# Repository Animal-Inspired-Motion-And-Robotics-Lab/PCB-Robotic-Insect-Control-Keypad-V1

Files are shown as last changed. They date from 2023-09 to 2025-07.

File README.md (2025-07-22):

# Robotic-Insect-Control-Keypad-V1 (R.I.C.K.)

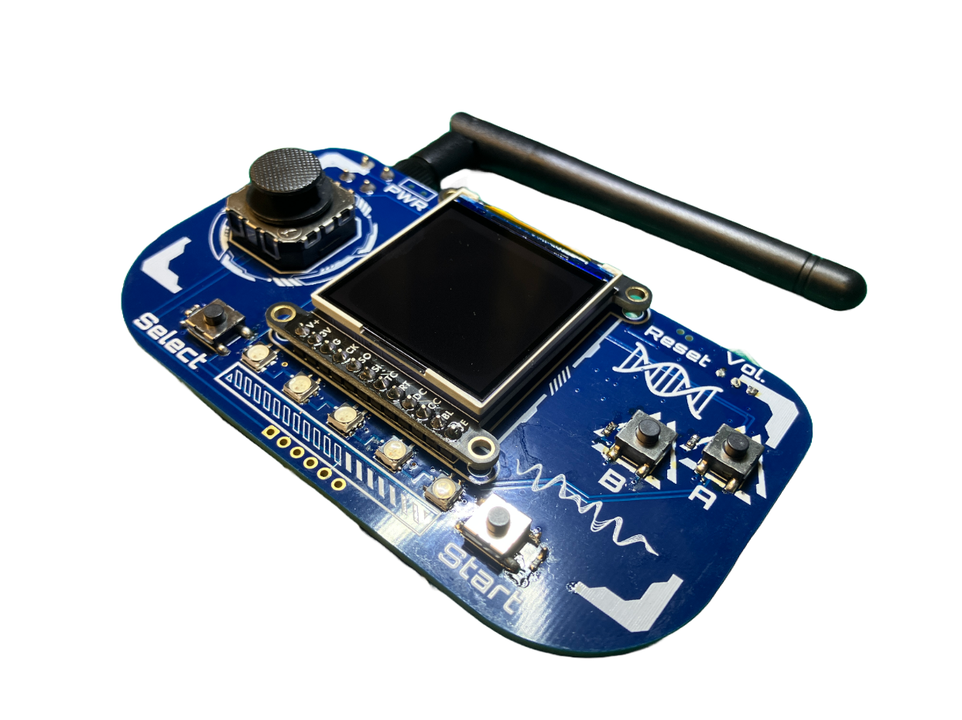
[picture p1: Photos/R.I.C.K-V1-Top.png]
R.I.C.K Top


## Description

The Robotic Insect Control Keypad (R.I.C.K.) is a programmable wireless controller based on the powerful ESP32-S3 WiFi/BLE capable MCU. The controller features a two axis joystick, four buttons, five NeoPixel LEDs, a 240x240 pixel TFT backlit display, speaker, accelerometer and a 400 mAh battery for portable play. The board is intended for use in controlling quadripedal robots or it can be used as an arcade platform for game development. Our lab (Animal Inspired Motion and Robotics Lab) will is currently using this controller during demos of our robot platforms.

## Features

1. 240x240 1.54" TFT screen with backlight
2. Two axis analog joystick and four user buttons
3. Five programmable NeoPixels
4. Integrated DAC, 2.5W amplifier and speaker
5. Three axis accelerometer
6.  400 mAh LiPo battery

## Block Diagram

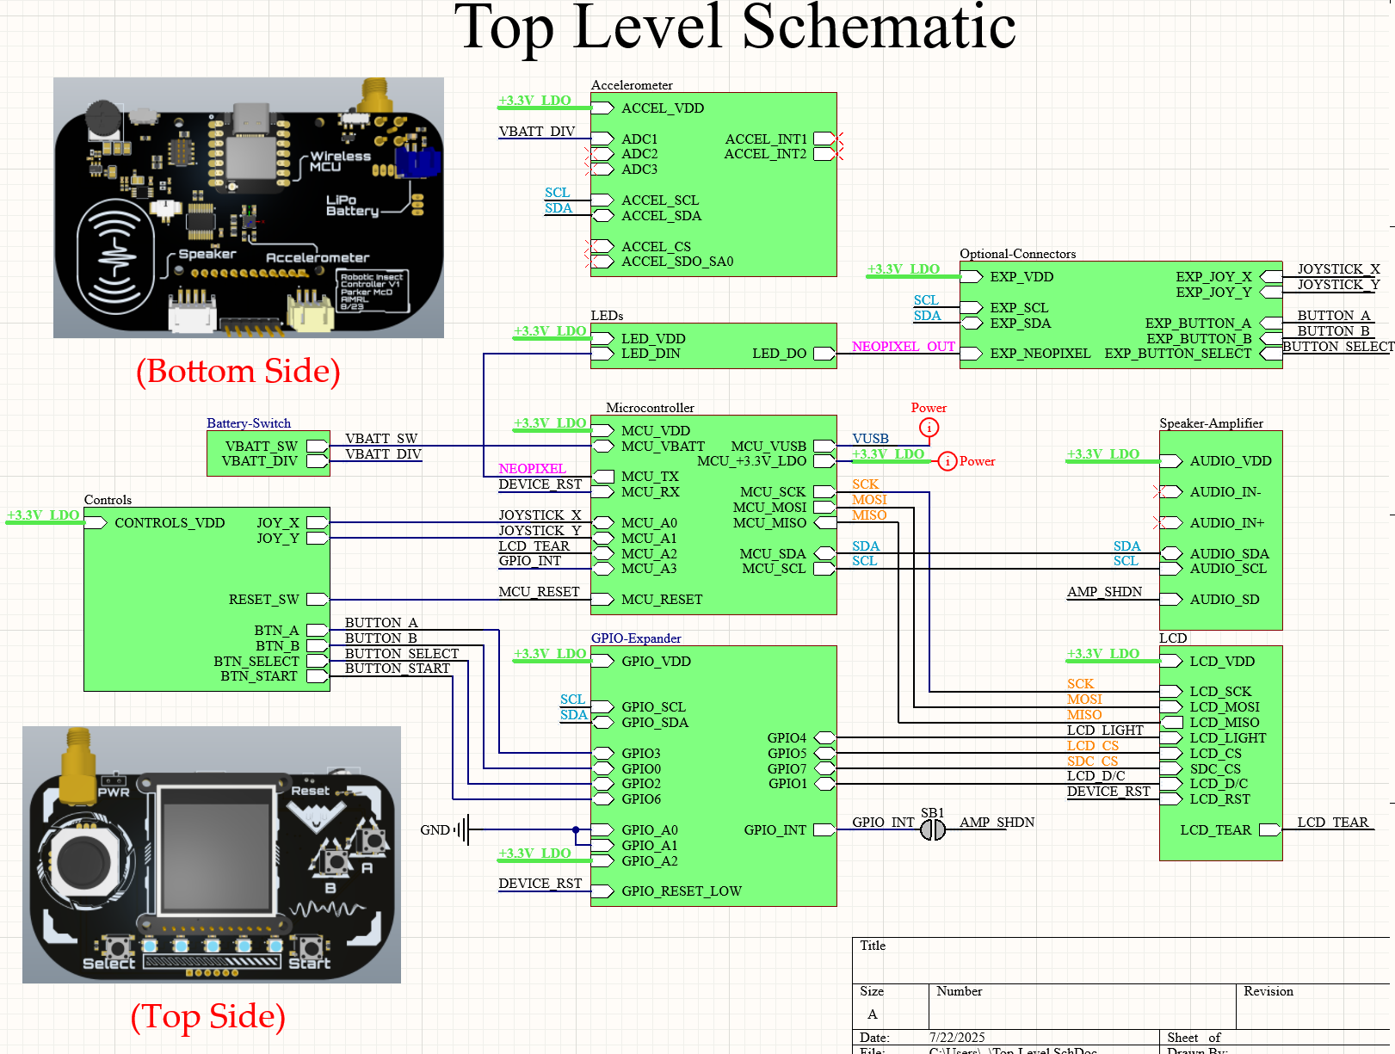
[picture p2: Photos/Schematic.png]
Block_Diagram


## Software

Coming soon! Currently under development.

## License

The board outline, joystick and buttons are based on the amazing [Adafruit Py Gamer](https://www.adafruit.com/product/4242)! Thanks Adafruit for making awesome stuff!

This work is licensed under the Creative Commons Attribution-ShareAlike 4.0 International License. To view a copy of this license, visit http://creativecommons.org/licenses/by-sa/4.0/ or send a letter to Creative Commons, PO Box 1866, Mountain View, CA 94042, USA.

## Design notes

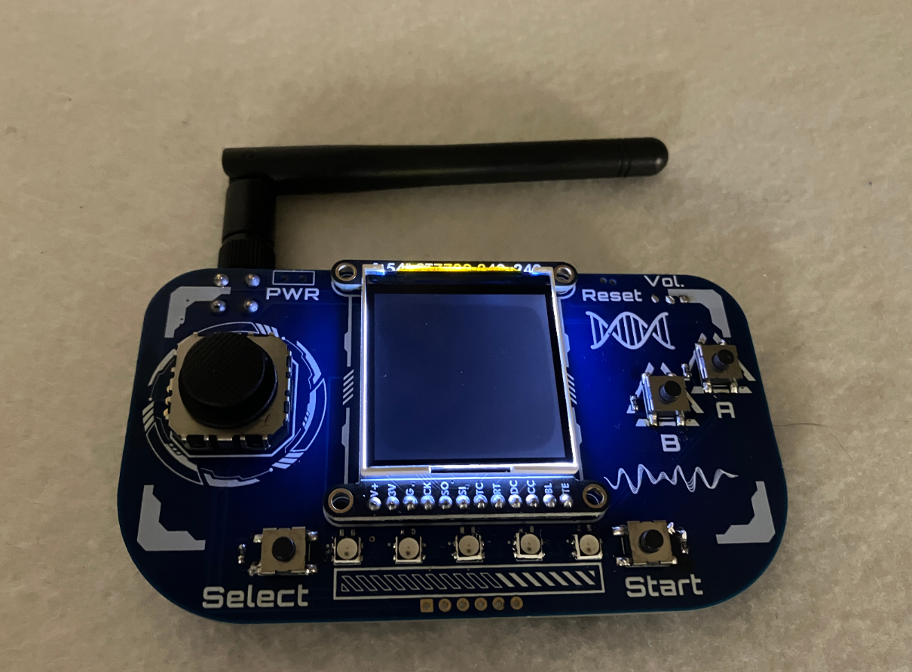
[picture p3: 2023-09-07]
Photos/R.I.C.K-V1-Top-Backlight.png

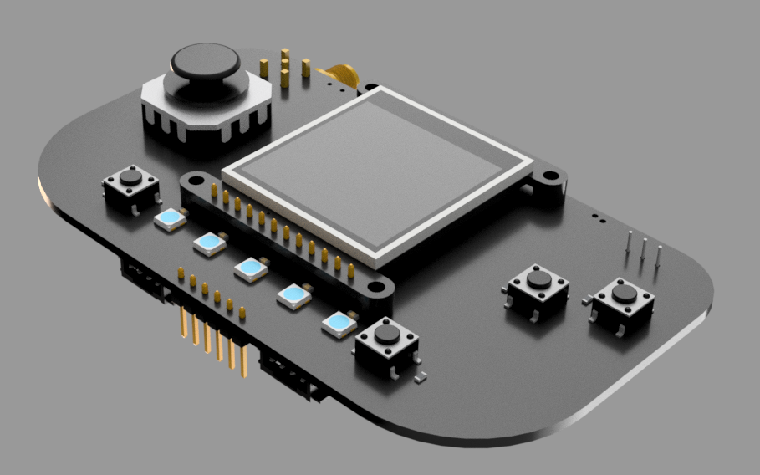
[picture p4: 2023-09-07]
Photos/R.I.C.K-Top-Right-Render.png

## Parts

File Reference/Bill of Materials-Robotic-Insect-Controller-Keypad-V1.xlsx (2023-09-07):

Line # | Designator | Populate | Footprint | Tolerance | Value | Part Number | Manufacturer Part Number 1 | Manufacturer 1 | Description
 | C1 |  | PCB-CAP-SMD-0603 |  | 10uF |  |  |  | Generic (no part number) 0603 surface mount capacitor
 | C2 |  | PCB-CAP-SMD-0603 |  | .1uF |  |  |  | Generic (no part number) 0603 surface mount capacitor
 | C3 |  | PCB-CAP-SMD-0603 |  | .1uF |  |  |  | Generic (no part number) 0603 surface mount capacitor
 | C4 |  | PCB-CAP-SMD-0603 |  | .1uF |  |  |  | Generic (no part number) 0603 surface mount capacitor
 | C5 |  | PCB-CAP-SMD-0603 |  | .1uF |  |  |  | Generic (no part number) 0603 surface mount capacitor
 | C6 |  | PCB-CAP-SMD-0603 |  | .1uF |  |  |  | Generic (no part number) 0603 surface mount capacitor
 | C7 |  | PCB-CAP-SMD-0603 |  | .1uF |  |  |  | Generic (no part number) 0603 surface mount capacitor
 | C8 |  | PCB-CAP-SMD-0603 |  | 10uF |  |  |  | Generic (no part number) 0603 surface mount capacitor
 | C9 |  | PCB-CAP-SMD-0603 |  | .1uF |  |  |  | Generic (no part number) 0603 surface mount capacitor
 | C10 |  | PCB-CAP-SMA-0805 |  | 10uF |  |  |  | Generic (no part number) 0805 surface mount resistor
 | C11 |  | PCB-CAP-SMD-0402 |  |  |  |  |  | Generic (no part number) 0402 surface mount capacitor
 | C12 |  | PCB-CAP-SMD-0402 |  | 1uF |  |  |  | Generic (no part number) 0402 surface mount capacitor
 | C13 |  | PCB-CAP-SMD-0402 |  |  |  |  |  | Generic (no part number) 0402 surface mount capacitor
 | C14 |  | PCB-CAP-SMD-0402 |  | 1uF |  |  |  | Generic (no part number) 0402 surface mount capacitor
 | C15 |  | PCB-CAP-SMD-0402 |  |  |  |  |  | Generic (no part number) 0402 surface mount capacitor
 | C16 |  | PCB-CAP-SMD-0603 |  | 10uF |  |  |  | Generic (no part number) 0603 surface mount capacitor
 | J1 |  | PCB-CONN-PIN-HEADER-6-PIN-100-MIL |  |  | Pin Header |  |  | PinHeader 1x6 TH Pitch 2.54mm
 | JOY1 |  | PCB-JOYSTICK-ANALOG_MINITHM |  |  |  |  |  | 2-Axis analog joystick
 | LCD1 |  | PCB-PCB-1.7X1.6-INCHES-DISP-LCD_QT154H2201 |  |  | 618 |  |  | Adafruit 1.54" 240x240 Wide Angle TFT LCD Display with MicroSD - ST7789 with EYESPI Connector
 | M1 |  | PCB-SOT-23 |  |  |  |  |  | MOSFET P-CH 20V 1.3A SOT-23
 | R1 |  | PCB-RES-SMD-0805 |  | 4.7K |  |  |  | Generic (no part number) 0805 surface mount resistor
 | R2 |  | PCB-RES-SMD-0603 |  | 10K |  |  |  | Generic (no part number) 0603 surface mount resistor
 | R3 |  | PCB-RES-SMD-0603 |  | 10K |  |  |  | Generic (no part number) 0603 surface mount resistor
 | R4 |  | PCB-RES-SMD-0603 |  | 10K |  |  |  | Generic (no part number) 0603 surface mount resistor
 | R5 |  | PCB-RES-SMD-0603 |  | 10K |  |  |  | Generic (no part number) 0603 surface mount resistor
 | R6 |  | PCB-RES-SMD-0603 |  | 10K |  |  |  | Generic (no part number) 0603 surface mount resistor
 | R7 |  | PCB-RES-SMD-0603 |  | 10K |  |  |  | Generic (no part number) 0603 surface mount resistor
 | R8 |  | PCB-RES-SMD-0603 |  | 10K |  |  |  | Generic (no part number) 0603 surface mount resistor
 | R9 |  | PCB-RES-SMD-0805 |  | 4.7K |  |  |  | Generic (no part number) 0805 surface mount resistor
 | R10 |  | PCB-RES-SMD-0805 |  | 10K |  |  |  | Generic (no part number) 0805 surface mount resistor
 | R11 |  | PCB-RES-SMD-0805 |  | 1K |  |  |  | Generic (no part number) 0805 surface mount resistor
 | R12 |  | PCB-RES-SMD-0805 |  | 10K |  |  |  | Generic (no part number) 0805 surface mount resistor
 | R13 |  | PCB-RES-SMD-0603 |  | 10K |  |  |  | Generic (no part number) 0603 surface mount resistor
 | R14 |  | PCB-RES-SMD-0603 |  | 10K |  |  |  | Generic (no part number) 0603 surface mount resistor
 | R15 |  | PCB-RES-SMD-0603 |  | 10K |  |  |  | Generic (no part number) 0603 surface mount resistor
 | R16 |  | PCB-RES-SMD-0603 |  | 100K |  |  |  | Generic (no part number) 0603 surface mount resistor
 | R17 |  | PCB-RES-SMA-0402 |  | 5k |  |  |  | Generic (no part number) 0402 surface mount resistor
 | R19 |  | PCB-RES-SMA-0402 |  | 5k |  |  |  | Generic (no part number) 0402 surface mount resistor
 | R20 |  | PCB-RES-SMA-0402 |  | 100R |  |  |  | Generic (no part number) 0402 surface mount resistor
 | R21 |  | PCB-RES-SMA-0402 |  | 100R |  |  |  | Generic (no part number) 0402 surface mount resistor
 | R22 |  | PCB-RES-SMA-0402 |  | 100R |  |  |  | Generic (no part number) 0402 surface mount resistor
 | R23 |  | PCB-RES-SMA-0402 |  | 100R |  |  |  | Generic (no part number) 0402 surface mount resistor
 | SW2 |  | PCB-SMD-SWITCH-6MM |  |  |  |  |  | 6mm diameter tactile switch.
 | SW3 |  | PCB-SMD-SWITCH-6MM |  |  |  |  |  | 6mm diameter tactile switch.
 | SW4 |  | PCB-SMD-SWITCH-6MM |  |  |  |  |  | 6mm diameter tactile switch.
 | SW5 |  | PCB-SMD-SWITCH-6MM |  |  |  |  |  | 6mm diameter tactile switch.
 | U2 |  | PCB-SK6812B-3535-SMD-3.5X3.7MM |  |  |  | 2659 | Adafruit Industries | 3.5x3.7x1.1 mm 0.2W Intelligent external control surface
 | U3 |  | PCB-SK6812B-3535-SMD-3.5X3.7MM |  |  |  | 2659 | Adafruit Industries | 3.5x3.7x1.1 mm 0.2W Intelligent external control surface
 | U4 |  | PCB-SK6812B-3535-SMD-3.5X3.7MM |  |  |  | 2659 | Adafruit Industries | 3.5x3.7x1.1 mm 0.2W Intelligent external control surface
 | U5 |  | PCB-SK6812B-3535-SMD-3.5X3.7MM |  |  |  | 2659 | Adafruit Industries | 3.5x3.7x1.1 mm 0.2W Intelligent external control surface
 | U6 |  | PCB-SK6812B-3535-SMD-3.5X3.7MM |  |  |  | 2659 | Adafruit Industries | 3.5x3.7x1.1 mm 0.2W Intelligent external control surface
 | SW7 |  | PCB-SPDT_SMT_SSSS811101 |  |  |  | SSSS811101 | Alps Electric | Toggle switch
 | R18 |  | PCB-FP-3352T-MFG | 20% | 10kR |  | 3352T-1-103LF | Bourns | Trimmer Potentiometer 10k Ohm 20% 1/2 Watt 1 Turn Pin Through Hole
 | U9 |  | PCB-MSOP-8-.65MM |  |  | PAM8302AASCR | PAM8302AASCR | Diodes | IC AMP AUDIO 2.5W CLASS D 8MSOP
 | DEV1 |  | PCB-ESP32-S3-XIAO-SMD |  |  | ESP32-S3 XIAO | ESP32-S3 | Espressif Systems | SMD IC ESP32-S3, Dual-core MCU with WiFi and BLE support.
 | SW6 |  | PCB-SPST-TACTILE-RA |  |  | TL3330AF260QG | TL3330AF260QG | E-Switch | Switch Tactile N.O. SPST Rectangular Button Gull Wing 0.05A 12VDC 2.55N SMD
 | BT1 |  | PCB-CONN-JST- S2B-PH-SM4-TB(LF)(SN)-2_V |  |  |  | S2BPHSM4TBLFSN | JST | Connector Header, PH Series, 2 Position, Side Entry, 2.00mm, Solder, Surface Mount, Natural for connecting to a battery.
 | J4 |  | PCB-CONN-JST- S4B-PH-SM4-TB(LF)(SN)3 |  |  |  | S4B-PH-SM4-TB(LF)(SN) | JST | Connector Header, PH Series, 4 Position, Side Entry, 2.00mm, Solder, Surface Mount, Natural.
 | J? |  | PCB-CONN-JST- S4B-PH-SM4-TB(LF)(SN)3 |  |  |  | S4B-PH-SM4-TB(LF)(SN) | JST | Connector Header, PH Series, 4 Position, Side Entry, 2.00mm, Solder, Surface Mount, Natural.
 | J2 |  | PCB-CON-SMA-RA-NO-FEED |  |  |  | CONREVSMA002 | Linx | RP-SMA Connector Right Angle Jack (Female), PCB Through-Hole Mount, Nickel
 | U7 |  | PCB-TSSOP-20-.65MM-7.2x5.2MM |  |  | MCP23008T-E/SS | MCP23008T-E/SS | Microchip | MCP23008 Series 5.5 V 1.7 MHz 8-Bit I/O Expander with Serial Interface - SSOP-20
 | U8 |  | PCB-MCP4725-MSOP-10-3X3MM |  |  |  | MCP4725A0T-E/CH | Microchip | IC DAC 12BIT W/I2C SOT23A-6
 | P1 |  | PCB-PICOBLADE-2PIN-1.25MM |  |  |  | 53261-0271 | Molex | 1.25mm Pitch PicoBlade™ Header, Surface Mount, Right Angle, Lead-Free, 2 Circuits
 | FB1 |  | PCB-SMD-FERRITE-0402 |  |  |  | BLM15AG100SN1D | Murata | Generic (no part number) 0402 ferrite bead
 | FB2 |  | PCB-SMD-FERRITE-0402 |  |  |  | BLM15AG100SN1D | Murata | Generic (no part number) 0402 ferrite bead
 | FB3 |  | PCB-SMD-FERRITE-0402 |  |  |  | BLM15AG100SN1D | Murata | Generic (no part number) 0402 ferrite bead
 | J3 |  | PCB-BOX-HEADER-10PIN-FP-FTSH-105-01-L-DV-K-P-T-MFG |  |  | FTSH-105-01-L-DV-K-P-TR | FTSH-105-01-L-DV-K-P-TR | Samtec | Conn Unshrouded Header HDR 10 POS 1.27mm Solder ST Top Entry SMD T/R
 | U1 |  | PCB-LGA16_3X3MM |  |  | LIS3DHTR | LIS3DHTR | STMicroelectronics | LIS3DHTR 3-Axis Accelerometer with I2C/SPI Interface VDD: 1.71-3.6V VDDIO: 1.71-VDD+0.1V Scale: +/-2g, 4g, 8g, 16g with 16--bit data output Temp:: -40Â°C - 85Â°C Mouser: 511-LIS3DHTR Digikey: 497-10613-1-ND

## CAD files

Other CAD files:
3D CAD/Robotic-Insect-Control-Keypad-V1.f3d

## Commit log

2023-09-07 Added design files, fabrication files, references, datasheets and photos of the board.
    [Accelerometer.SchDoc, Battery-Switch.SchDoc, Bill of Materials-Robotic-Insect-Controller-Keypad-V1.xlsx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]
2023-09-07 Added 3D CAD of PCB in STEP, F3D and X_T
    [Robotic-Insect-Control-Keypad-V1.f3d]
